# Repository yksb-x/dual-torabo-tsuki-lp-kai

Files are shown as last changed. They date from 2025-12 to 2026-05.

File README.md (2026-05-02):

# Dual-Torabo-Tsuki-LP改（仮）

torabo-tsuki lpは、せきごん氏によって設計された、トラックボール搭載の薄型（ロープロファイル）分割型ワイヤレスキーボードです。
本プロジェクトでは、この torabo-tsuki lp をより自分好みに最適化するため、PCB（プリント基板）の設計変更やケースの改造に取り組むことを目的としています。

## やりたい事
- 自分はMサイズを購入して使用しているが、Sサイズに近い構成で制作する。
- 電池のプラスマイナスを逆に取り付けられる様に配線を変更する。（縦型デザインの乾電池が正しい向きで見える様にする）
- トラックボールはデュアル前提とする。
- その上で、親指キーを左右３つずつ配置する
- トラックボールは19mm球を前提とする。
- ボトムプレート、トラボケースをケースと一体にして、高さ的にトラボが出っ張らない様にする。
- 電池カバーをもっと開閉しやすくする。（現状ノーアイデア）
- 持ち運び用のカバー（弁当箱みたいに上から被せる）
- テンティング（上記のカバーを左右逆にして底側から被せるとテンティングで使えます。みたいなやつ）

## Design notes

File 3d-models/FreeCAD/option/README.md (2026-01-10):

# シンプルケース

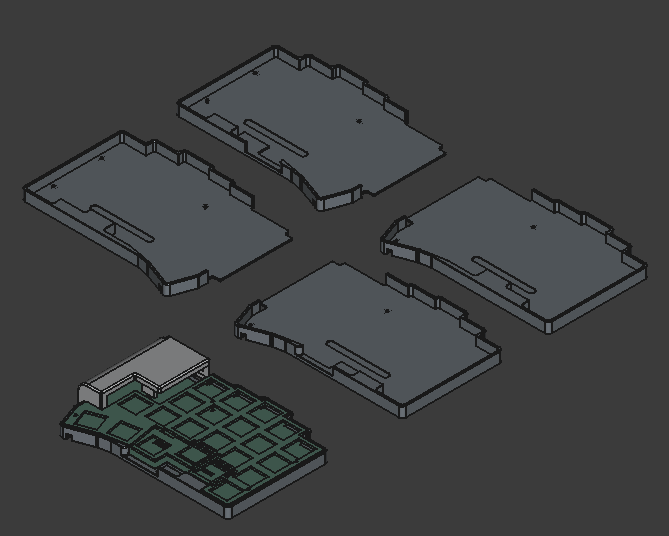
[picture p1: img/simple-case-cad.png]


S/M/Lに対応したケースの設計データです。FreeCADで開いて、スプレッドシートの`case_w_offset`を19にするとMサイズ用、`case_w_offset`と`case_h_offset`を19にするとLサイズ用になります。

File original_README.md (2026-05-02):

# torabo-tsuki LP

torabo-tsuki LP（トラボ付きLP）はトラックボール付きの無線分割キーボードキットです。

トラックボール(25 or 19mm)の高さを低く抑えることで、キーを打つときや持ち運びの邪魔になりにくくなっています。
無線接続に適したハードウェア・ソフトウェア構成により低消費電力を実現しており、連続して数か月間使用可能です。バッテリーは乾電池なので、残量や安全性を気にしながら定期的に充電する必要がありません。

[BOOTH](https://nogikes.booth.pm/items/7200248)にて販売中です。

**MX版の情報は[こちら](https://github.com/sekigon-gonnoc/torabo-tsuki)**

|||
|-|-|
|Sサイズ, 右25mmボール, ケースなし|Sサイズ, 右25mmボール, ケースなし|
|||
|Sサイズ, 右19mmボール, ケースなし|Sサイズ, 右19mmボール, ケースなし|
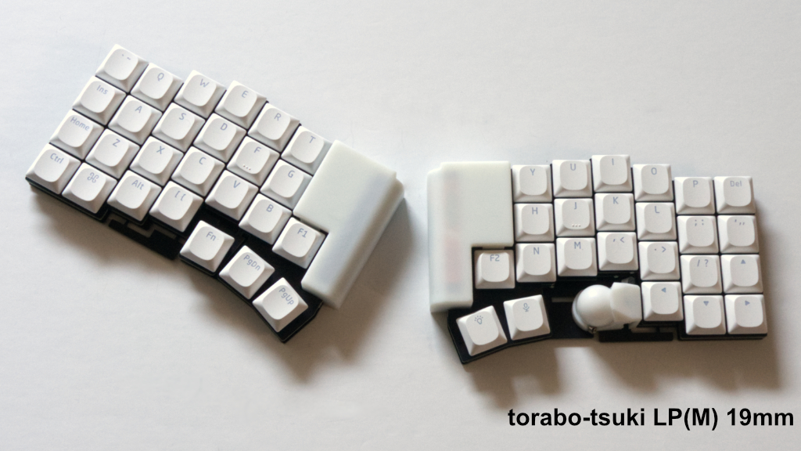
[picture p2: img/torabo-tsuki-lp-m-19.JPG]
|||
|Mサイズ, 右19mmボール, ケースなし||
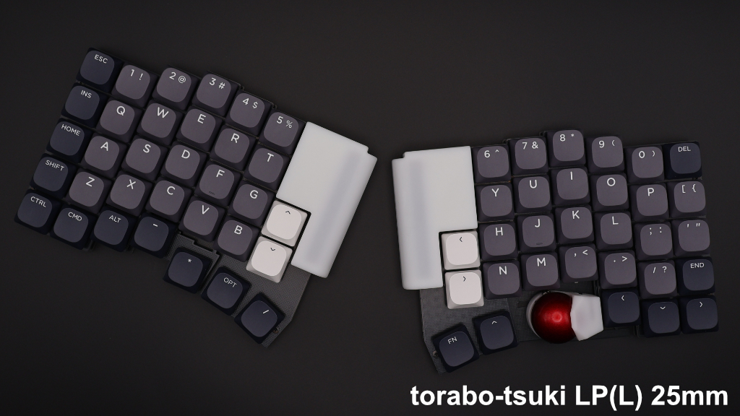
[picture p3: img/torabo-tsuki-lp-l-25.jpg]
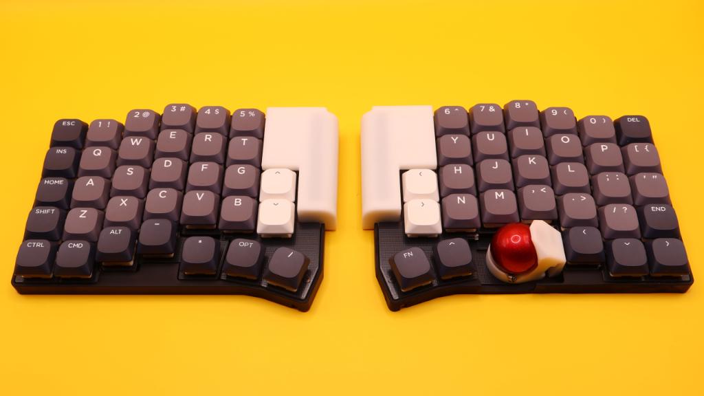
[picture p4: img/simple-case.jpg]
|||
|Lサイズ, 右25mmボール, ケースなし|Lサイズ, シンプルケース|
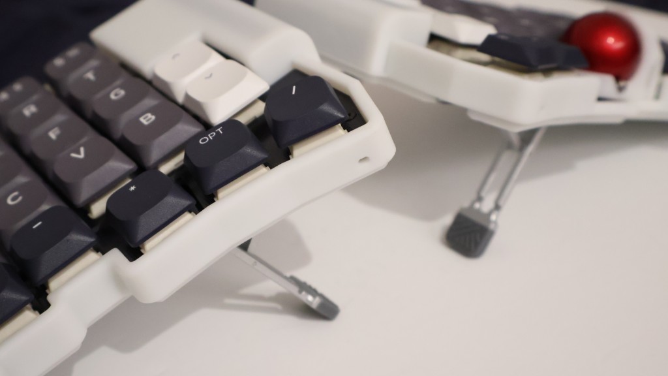
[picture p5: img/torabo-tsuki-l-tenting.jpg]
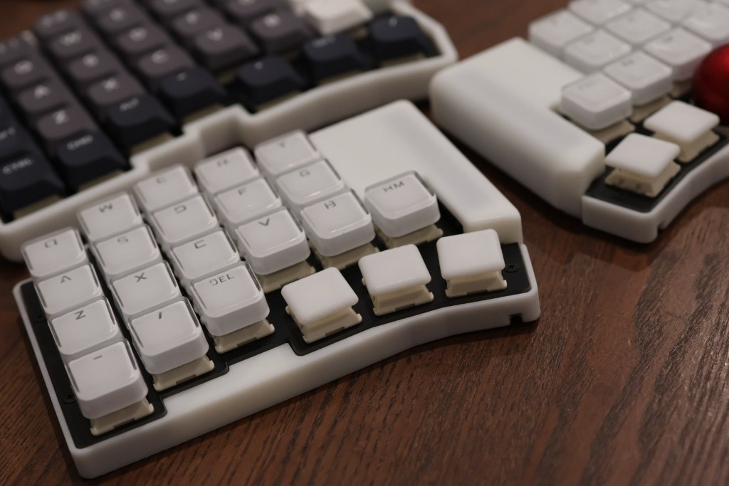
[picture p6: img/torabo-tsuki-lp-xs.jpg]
|||
|Lサイズ, テンティングケース|XSサイズ, 右25mmボール, シンプルケース|

## [ビルドガイド](build-guide.md)

## 特徴

* 主要部品実装済み
  * ソケットやダイオードなどの部品は実装済みです。半田付けが必要な部品は電池ボックスだけです。
* 乾電池各1本で長期間動作
  * Ni-MH電池またはアルカリ電池で動作します。
  * 無線での使用にあわせて調整されたハードウェア・ソフトウェア構成により、乾電池でも数か月間利用できます。
* トラックボールの設置位置が調整可能
  * トラックボールを取り付ける位置を調整して、自分にとって一番操作しやすい位置に設置できます。ボールの高さを抑えたことでキーを打つときの邪魔になりにくなっています。
  * 左トラックボール、デュアルトラックボールにすることもできます。
  * トラックボールのサイズは25mmまたは19mmから選択できます。
* ZMK対応
  * keymap-editorやZMK Studioを使用して簡単にキーマップが変更できます。

## 使用上の注意

* 異臭や煙が出たときは、ただちに使用を中止して電源を切り電池を抜いてください。
* 電池から漏れた液が目に入った場合は、失明する恐れがあるのですぐにきれいな水でよく洗い、医師の診断を受けてください。
* 電池の+-を正しくセットしてください。
* 使い切った電池は速やかに取り出してください。
* 長期間使用しない場合は電池を取り出してください。

## 設計データについて

本リポジトリで基板・トラックボールケース・電池カバーの設計データを公開しています。

ライセンスにしたがって自由に利用していただいて構いませんが、問い合わせには対応しません。

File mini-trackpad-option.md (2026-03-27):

# ミニトラックパッドオプション

トラックボールを付けていない側の電池カバーに、小型のトラックパッドを取り付けるオプションです。

デフォルトでは高分解能スクロールに利用できます。

## オプションキットに含まれているもの

* ミニトラックパッド
* 150mm FPC

## オプションパーツ以外に必要なもの

* 両面テープ（はがしやすいタイプがおすすめです）

## 組み立て

* [トラックパッド対応の電池カバー](3d-models/STL/option/mini-trackpad/)を作成する
  * FDM方式で作成する場合、インフィルを100%にしないと正しく動作しない可能性が高いです。（JLCのSLA方式で製造したもののみ動作確認しています）
* 両面テープをトラックパッドの全面に貼りつけて、電池カバーに取り付ける

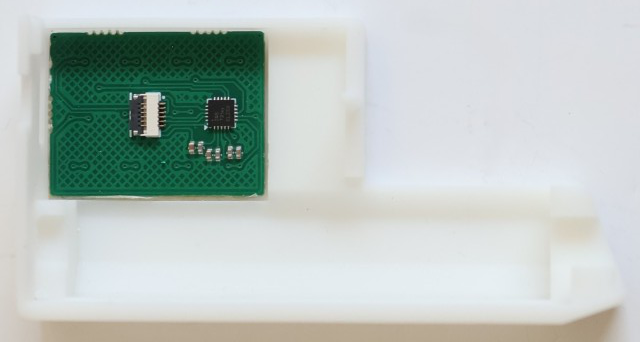
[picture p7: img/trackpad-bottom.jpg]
  ||
  |-|

* FPCケーブルを電池ボックスの側面に通し、キーボードとトラックパッドを接続する

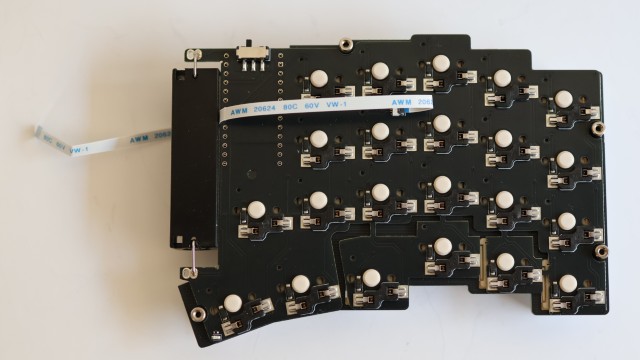
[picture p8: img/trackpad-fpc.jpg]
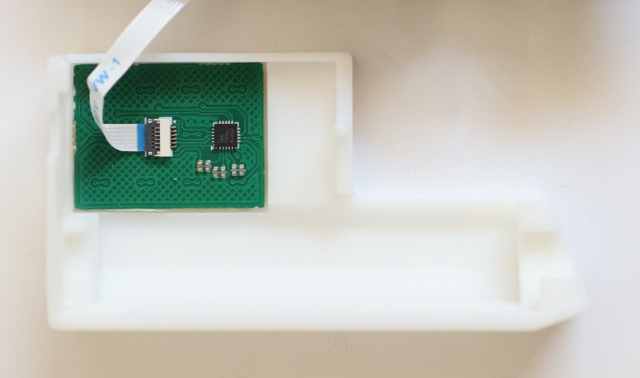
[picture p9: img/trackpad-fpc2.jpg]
  |||
  |-|-|

* 電池カバーをキーボード本体に取り付ける
  * FPCケーブルがBMP Boostのアンテナ部を覆ったり、コンスルーと電池カバーの間に挟まったりしないように注意してください 

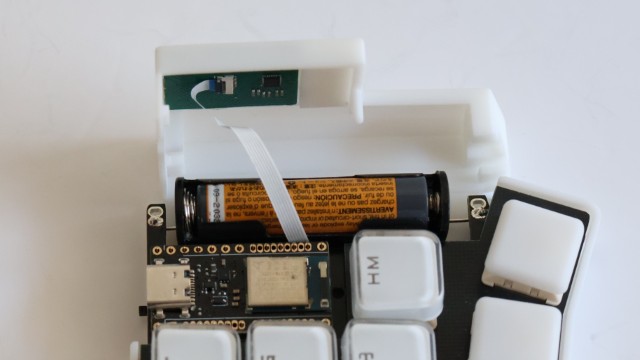
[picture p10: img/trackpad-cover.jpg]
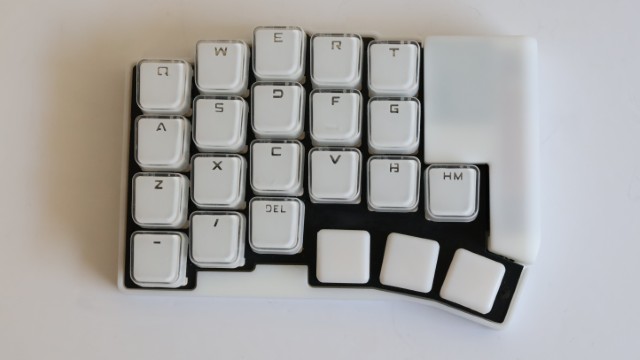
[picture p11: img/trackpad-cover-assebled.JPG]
  |||
  |-|-|

## ファームウェア

[build.yaml](https://github.com/sekigon-gonnoc/zmk-keyboard-torabo-tsuki-lp/blob/master/build.yaml)を編集し、トラックボール側のスニペットに`input-split-listener`、トラックパッド側のスニペットに`input-trackpad-mini`を追加してビルド

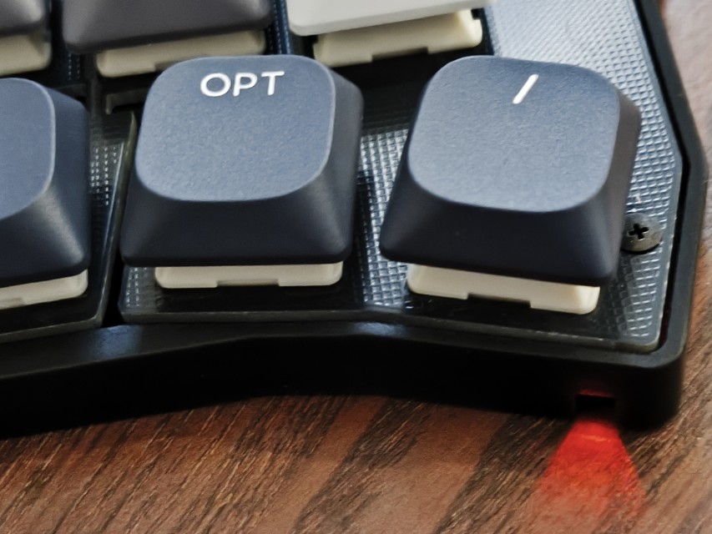
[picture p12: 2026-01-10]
img/simple-case-led.jpg

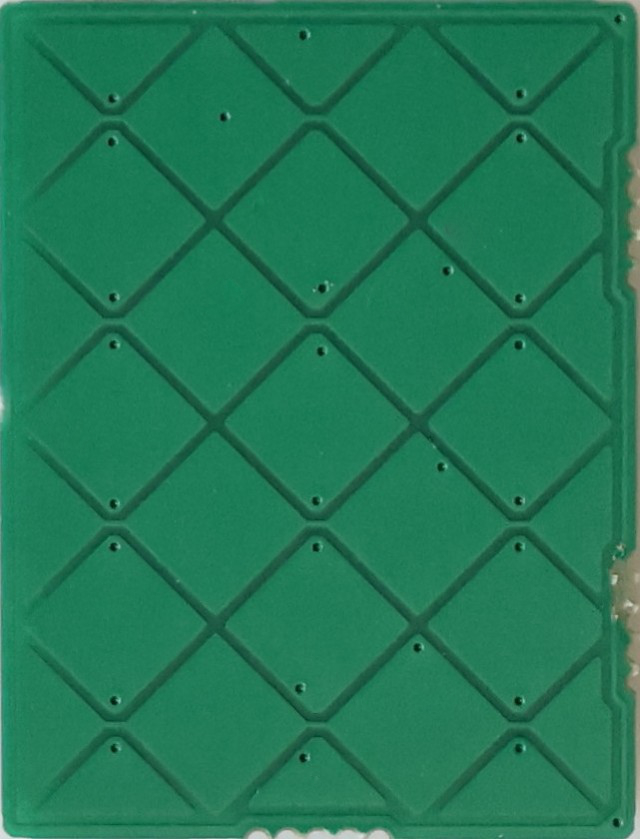
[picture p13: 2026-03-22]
img/trackpad-top.jpg

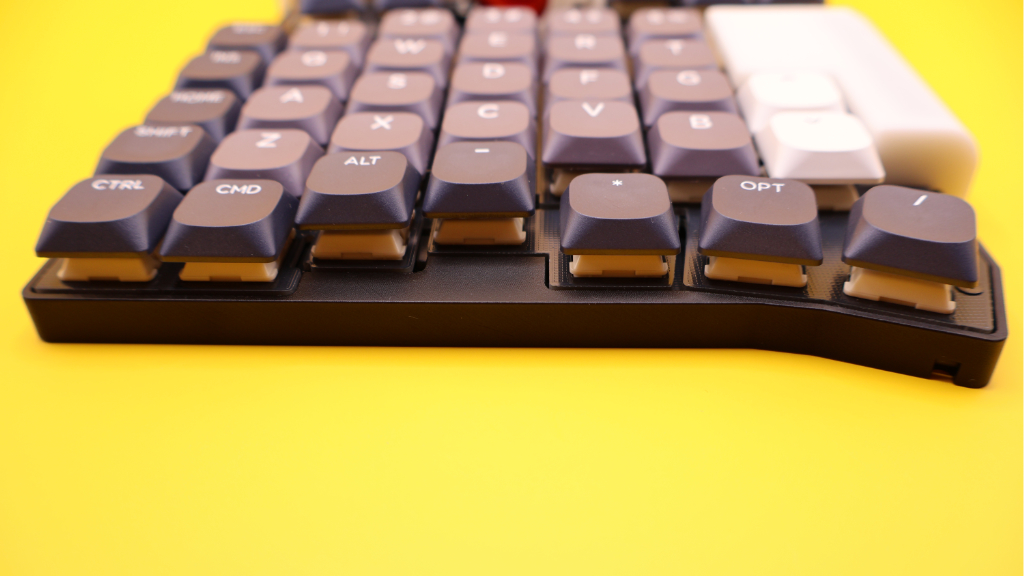
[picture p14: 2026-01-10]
img/simple-case-front.jpg

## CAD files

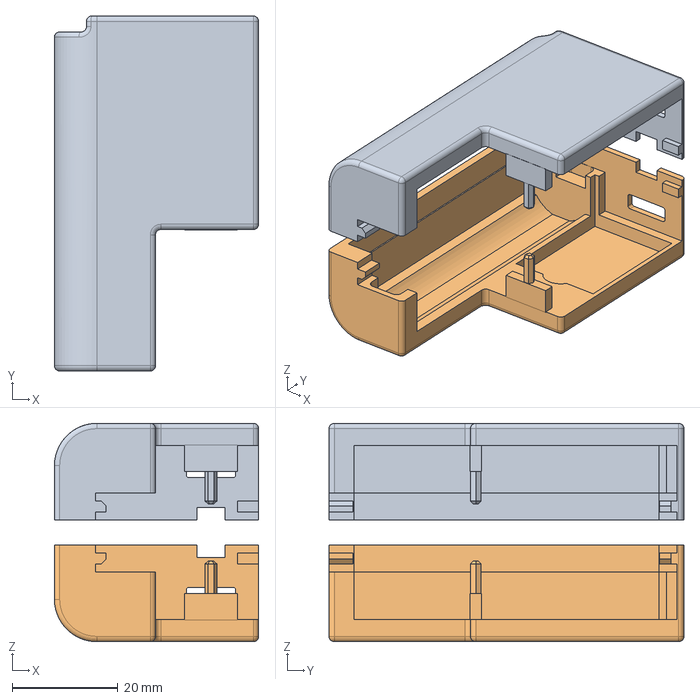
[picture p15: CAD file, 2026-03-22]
3d-models/FreeCAD/option/controller-cover-aa-trackpad.FCStd
38.5 x 67.0 x 41.2 mm
Body (Mirror #1)

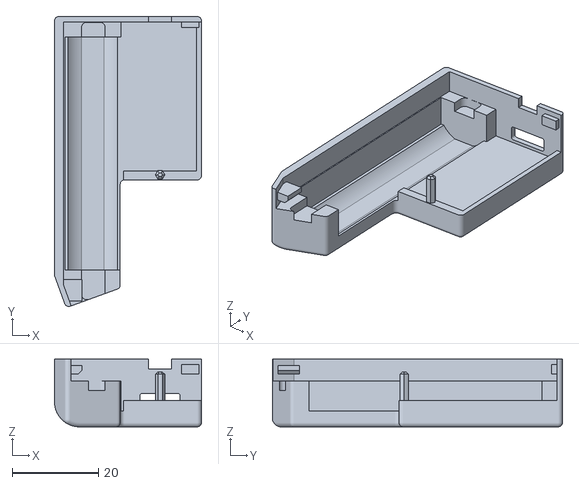
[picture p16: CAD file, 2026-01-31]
3d-models/STL/controller-cover-aaa-xs-Body-mirror.stl
34.1 x 67.2 x 15.7

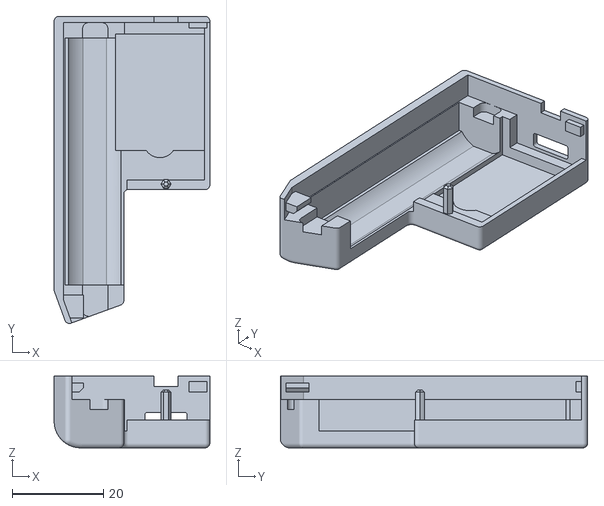
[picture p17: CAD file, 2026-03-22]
3d-models/STL/option/mini-trackpad/controller-cover-aaa-trackpad-xs-Body-mirror.stl
34.1 x 67.2 x 15.7

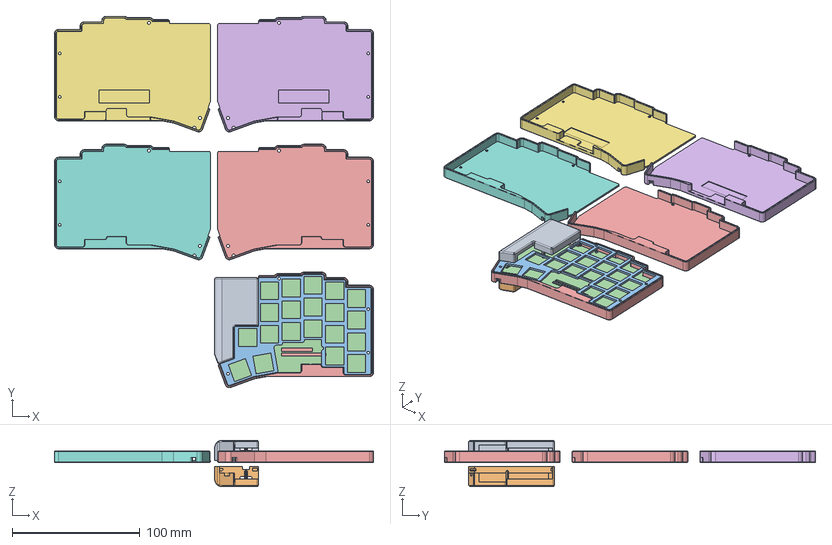
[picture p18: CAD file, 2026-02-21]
3d-models/FreeCAD/option/torabo-tsuki-lp-xs-simple-case.FCStd
249.4 x 290.4 x 36.2 mm
Body (Mirror #1)
torabo-tsuki-lp-XS-top_PCB
torabo-tsuki-lp-XS-bottom_PCB
case-key x 2
case-trackball x 2
case-trackball001 (Mirror #2)
case-key001 (Mirror #3)

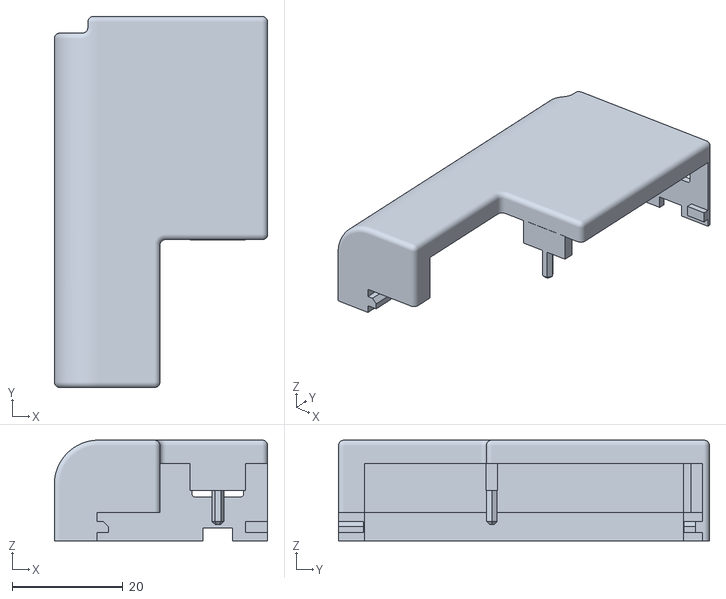
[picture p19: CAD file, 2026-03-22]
3d-models/STL/option/mini-trackpad/controller-cover-aa-trackpad-Body.stl
38.5 x 67.0 x 18.2

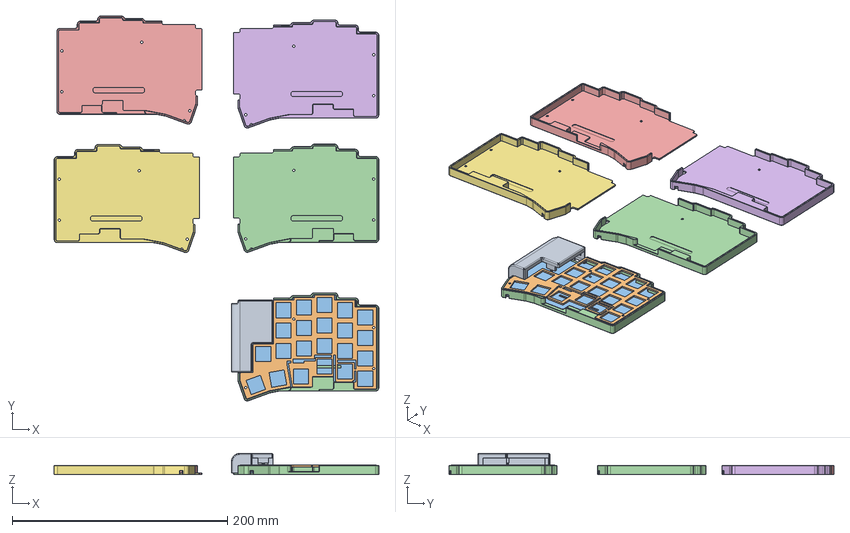
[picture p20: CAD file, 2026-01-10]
3d-models/FreeCAD/option/torabo-tsuki-lp-simple-case.FCStd
301.7 x 357.8 x 19.7 mm
torabo-tsuki-lp-S-top_PCB
torabo-tsuki-lp-S-bottom_PCB
トラックボール側 x 2
トラックボール側001 (Mirror #2)
キー側
キー側001 (Mirror #3)

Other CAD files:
3d-models/FreeCAD/option/controller-cover-aaa-trackpad-xs.FCStd
3d-models/STL/controller-cover-aaa-xs-Body.stl
3d-models/STL/option/mini-trackpad/controller-cover-aaa-trackpad-xs-Body.stl
3d-models/STL/option/mini-trackpad/controller-cover-aa-trackpad-Body-mirror.stl

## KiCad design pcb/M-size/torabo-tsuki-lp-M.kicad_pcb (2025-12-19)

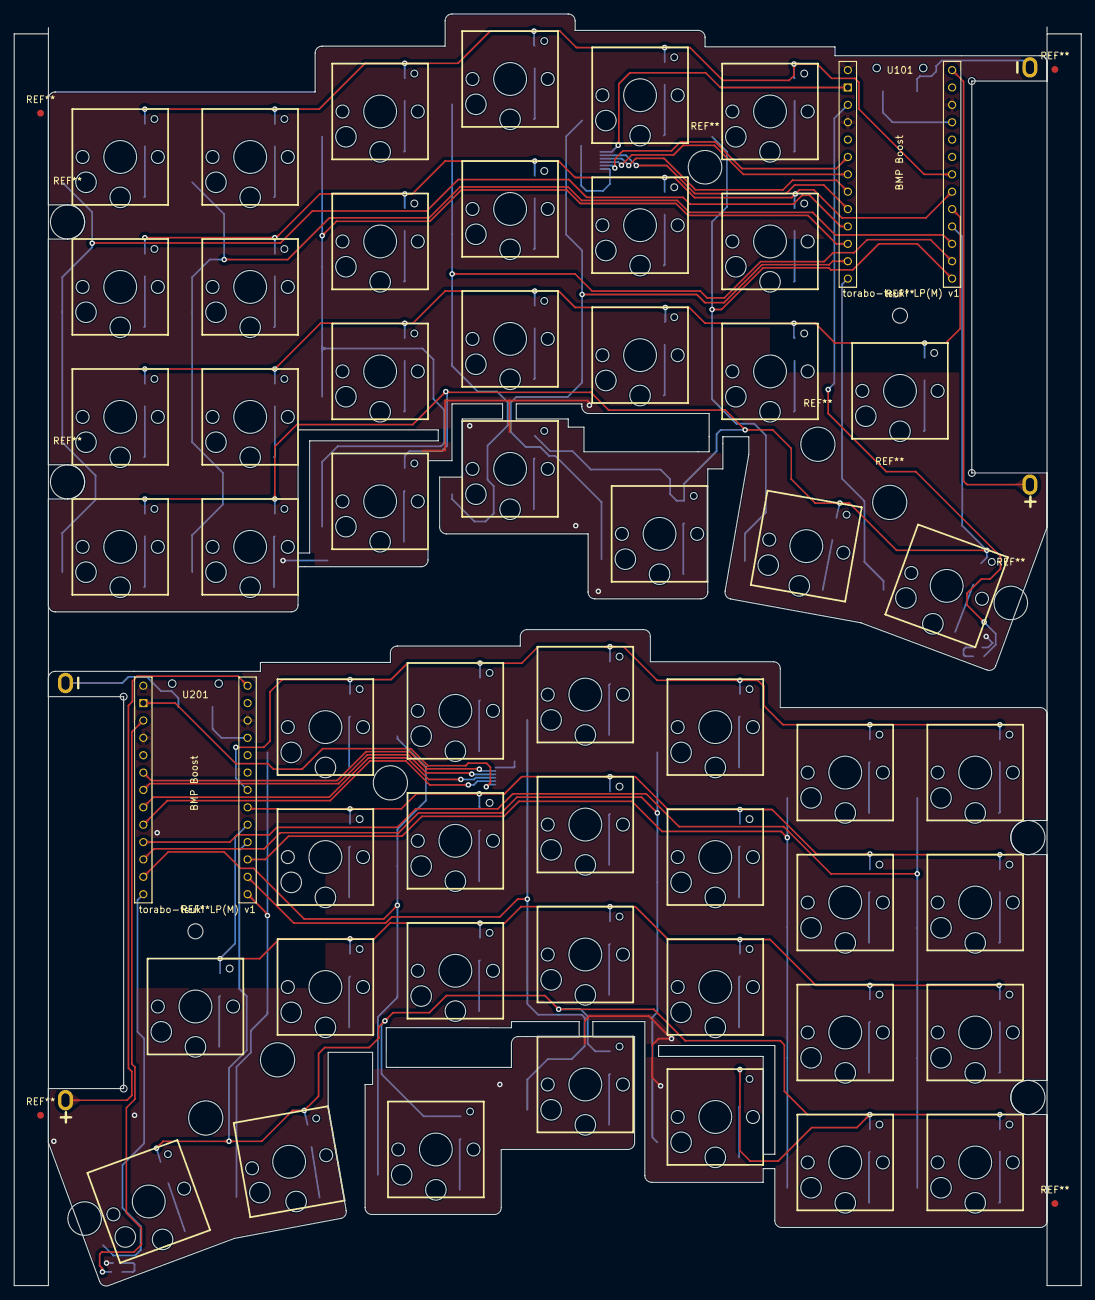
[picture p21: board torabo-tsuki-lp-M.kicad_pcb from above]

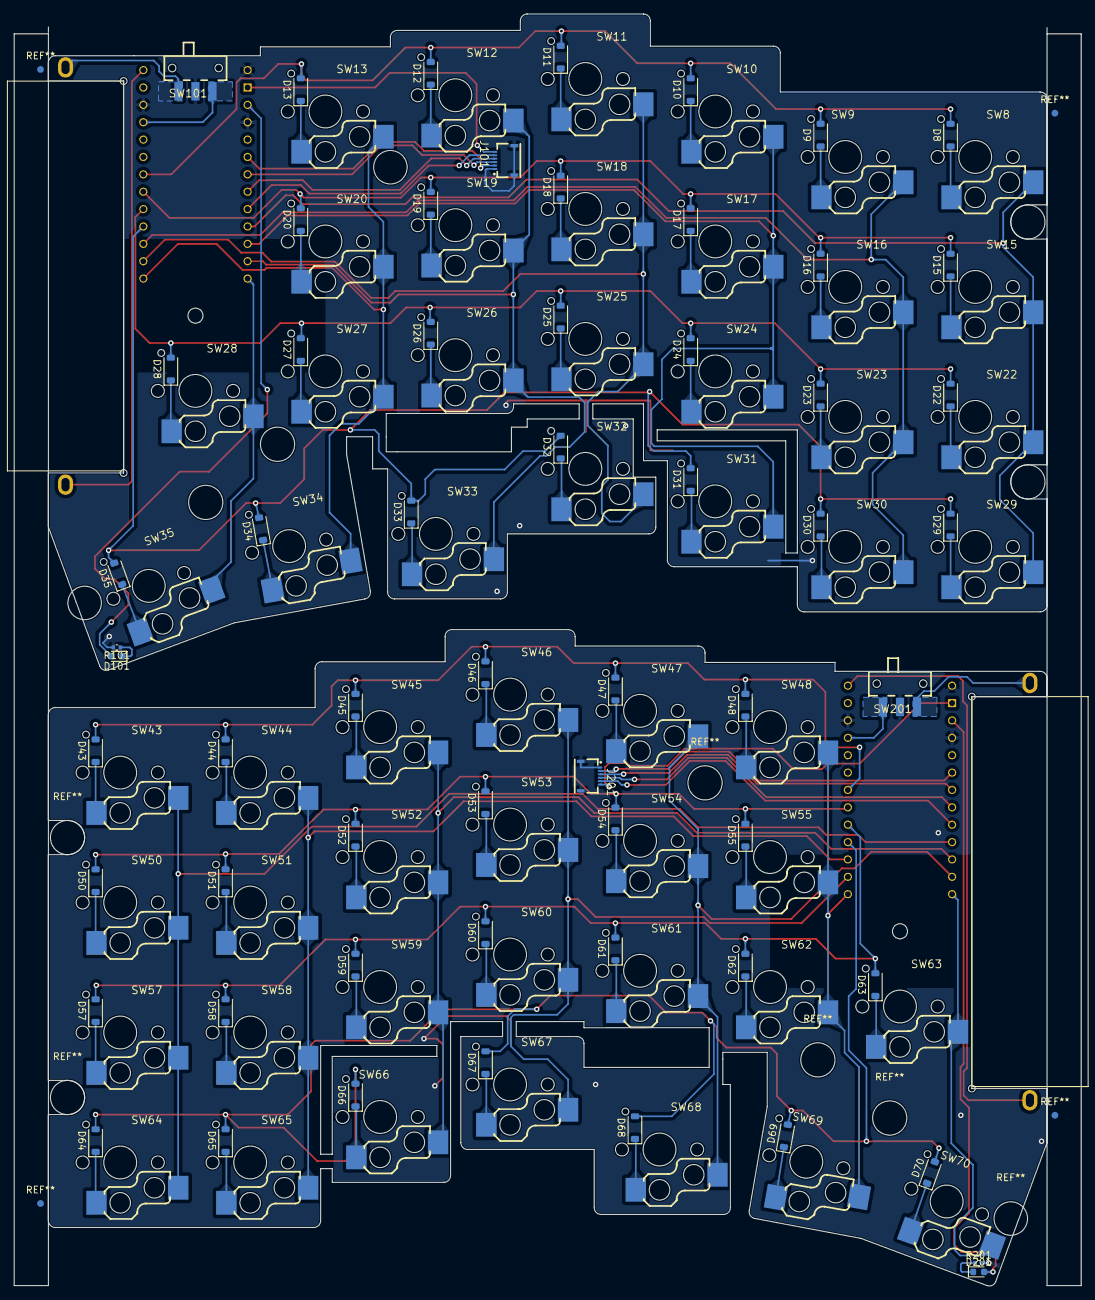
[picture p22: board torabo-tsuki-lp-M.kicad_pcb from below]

Board: 2 copper layers, 156.0 x 186.0 mm, 116 parts (114 on the bottom side), 93 nets.

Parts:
BT101, BT201: Battery_Cell; battery_holder
D8, D9, D10, D11, D12, D13, D15, D16, D17, D18, D19, D20, D22, D23, D24, D25, D26, D27, D28, D29, D30, D31, D32, D33, D34, D35, D43, D44, D45, D46, D47, D48, D50, D51, D52, D53, D54, D55, D57, D58, D59, D60, D61, D62, D63, D64, D65, D66, D67, D68, D69, D70: D_Small; D_SOD-123
D101, D201: LED_Small; LED_0603_1608Metric
J101, J201: Conn_01x06_MountingPin; GT-F0501SR10-06S1101
R101, R201: 330; R_0402_1005Metric
SW8, SW9, SW10, SW11, SW12, SW13, SW15, SW16, SW17, SW18, SW19, SW20, SW22, SW23, SW24, SW25, SW26, SW27, SW28, SW29, SW30, SW31, SW32, SW33, SW34, SW35, SW43, SW44, SW45, SW46, SW47, SW48, SW50, SW51, SW52, SW53, SW54, SW55, SW57, SW58, SW59, SW60, SW61, SW62, SW63, SW64, SW65, SW66, SW67, SW68, SW69, SW70: SW_Push; CHOC_V2_SOCKET_HANDSOLDERING
SW101, SW201: SW_SPDT; SW-SMD_K3-1280S-F1
U101, U201: BLEMicroPro

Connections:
+BATT: BT101.1 (+), BT201.1 (+), U101.26 (BAT), U201.26 (BAT)
/left/BOOT: SW101.3 (C), U101.23 (BOOT)
/left/COL0: SW8.1, SW15.1, SW22.1, SW29.1, U101.10 (22)
/left/COL1: SW9.1, SW16.1, SW23.1, SW30.1, U101.16 (47)
/left/COL2: SW10.1, SW17.1, SW24.1, SW31.1, U101.11 (23)
/left/COL3: SW11.1, SW18.1, SW25.1, SW32.1, U101.15 (10)
/left/COL4: SW12.1, SW19.1, SW26.1, SW33.1, U101.12 (32)
/left/COL5: SW13.1, SW20.1, SW27.1, SW34.1, U101.14 (9)
/left/COL6: SW28.1, SW35.1, U101.13 (35)
/left/CS: J101.5, U101.9 (20)
/left/LED: D101.2 (A), U101.3 (11)
/left/MOTION: J101.4, U101.8 (19)
/left/ROW1: D8.2 (A), D9.2 (A), D10.2 (A), D11.2 (A), D12.2 (A), D13.2 (A), U101.20 (0)
/left/ROW2: D15.2 (A), D16.2 (A), D17.2 (A), D18.2 (A), D19.2 (A), D20.2 (A), U101.19 (30)
/left/ROW3: D22.2 (A), D23.2 (A), D24.2 (A), D25.2 (A), D26.2 (A), D27.2 (A), D28.2 (A), U101.18 (3)
/left/ROW4: D29.2 (A), D30.2 (A), D31.2 (A), D32.2 (A), D33.2 (A), D34.2 (A), D35.2 (A), U101.17 (46)
/left/SCLK: J101.2, U101.6 (18)
/left/SDIO: J101.3, U101.7 (16)
/right/BOOT: SW201.1 (A), U201.23 (BOOT)
/right/COL0: SW43.1, SW50.1, SW57.1, SW64.1, U201.10 (22)
/right/COL1: SW44.1, SW51.1, SW58.1, SW65.1, U201.16 (47)
/right/COL2: SW45.1, SW52.1, SW59.1, SW66.1, U201.11 (23)
/right/COL3: SW46.1, SW53.1, SW60.1, SW67.1, U201.15 (10)
/right/COL4: SW47.1, SW54.1, SW61.1, SW68.1, U201.12 (32)
/right/COL5: SW48.1, SW55.1, SW62.1, SW69.1, U201.14 (9)
/right/COL6: SW63.1, SW70.1, U201.13 (35)
/right/CS: J201.5, U201.9 (20)
/right/LED: D201.2 (A), U201.3 (11)
/right/MOTION: J201.4, U201.8 (19)
/right/ROW1: D43.2 (A), D44.2 (A), D45.2 (A), D46.2 (A), D47.2 (A), D48.2 (A), U201.20 (0)
/right/ROW2: D50.2 (A), D51.2 (A), D52.2 (A), D53.2 (A), D54.2 (A), D55.2 (A), U201.19 (30)
/right/ROW3: D57.2 (A), D58.2 (A), D59.2 (A), D60.2 (A), D61.2 (A), D62.2 (A), D63.2 (A), U201.18 (3)
/right/ROW4: D64.2 (A), D65.2 (A), D66.2 (A), D67.2 (A), D68.2 (A), D69.2 (A), D70.2 (A), U201.17 (46)
/right/SCLK: J201.2, U201.6 (18)
/right/SDIO: J201.3, U201.7 (16)
GND: J101.1, J101.MP (MountPin), J201.1, J201.MP (MountPin), R101.2, R201.2, SW101.2 (B), SW201.2 (B), U101.1 (GND), U101.4 (GND), U101.24 (GND), U201.1 (GND), U201.4 (GND), U201.24 (GND)
unnamed: BT101.2 (-), SW101.1 (A)
unnamed: BT201.2 (-), SW201.3 (C)
unnamed: D8.1 (K), SW8.2
unnamed: D9.1 (K), SW9.2
unnamed: D10.1 (K), SW10.2
unnamed: D11.1 (K), SW11.2
unnamed: D12.1 (K), SW12.2
unnamed: D13.1 (K), SW13.2
unnamed: D15.1 (K), SW15.2
unnamed: D16.1 (K), SW16.2
unnamed: D17.1 (K), SW17.2
unnamed: D18.1 (K), SW18.2
unnamed: D19.1 (K), SW19.2
unnamed: D20.1 (K), SW20.2
unnamed: D22.1 (K), SW22.2
unnamed: D23.1 (K), SW23.2
unnamed: D24.1 (K), SW24.2
unnamed: D25.1 (K), SW25.2
unnamed: D26.1 (K), SW26.2
unnamed: D27.1 (K), SW27.2
unnamed: D28.1 (K), SW28.2
unnamed: D29.1 (K), SW29.2
unnamed: D30.1 (K), SW30.2
unnamed: D31.1 (K), SW31.2
unnamed: D32.1 (K), SW32.2
unnamed: D33.1 (K), SW33.2
unnamed: D34.1 (K), SW34.2
unnamed: D35.1 (K), SW35.2
unnamed: D43.1 (K), SW43.2
unnamed: D44.1 (K), SW44.2
unnamed: D45.1 (K), SW45.2
unnamed: D46.1 (K), SW46.2
unnamed: D47.1 (K), SW47.2
unnamed: D48.1 (K), SW48.2
unnamed: D50.1 (K), SW50.2
unnamed: D51.1 (K), SW51.2
unnamed: D52.1 (K), SW52.2
unnamed: D53.1 (K), SW53.2
unnamed: D54.1 (K), SW54.2
unnamed: D55.1 (K), SW55.2
unnamed: D57.1 (K), SW57.2
unnamed: D58.1 (K), SW58.2
unnamed: D59.1 (K), SW59.2
unnamed: D60.1 (K), SW60.2
unnamed: D61.1 (K), SW61.2
unnamed: D62.1 (K), SW62.2
unnamed: D63.1 (K), SW63.2
unnamed: D64.1 (K), SW64.2
unnamed: D65.1 (K), SW65.2
unnamed: D66.1 (K), SW66.2
unnamed: D67.1 (K), SW67.2
unnamed: D68.1 (K), SW68.2
unnamed: D69.1 (K), SW69.2
unnamed: D70.1 (K), SW70.2
unnamed: D101.1 (K), R101.1
unnamed: D201.1 (K), R201.1
VCC: J101.6, J201.6, U101.2 (8), U201.2 (8)

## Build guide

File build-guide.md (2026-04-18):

## 同梱品

| 名称 | 数  |
| --- | --- |
| メイン基板 | 1 |
| トッププレート | 2 |
| ボトムプレート | 2 |
| 電池ボックス(単三 or 単四) | 2 |
| スペーサー(4.5mm) | 8 |
| ねじ(M2x3.5) | 18  |
| **トラックボール部品** | |
| トラックボールセンサー(14mmマウスセンサーモジュール) | 1 |
| フレキシブルケーブル(0.5mmピッチ、6P、100mm、電極同一面) | 1 |
| ベアリング(4x1.5x2 mm) | 3 |
| ねじ(M1.4) | 3 |
| **BMP Boost同梱の場合** | |
| BMP Boost | 2 |

## 別途必要な部品

| 名称 | 数 | 補足 |
| --- | ----- | --- |
| キースイッチ(Choc V2) | 42(S, XS), 50(M), 64(L) | |
| キーキャップ | 適量  | |
| 25mmトラックボール交換球  or 19.05mm POMボール | 1 | |
| コンスルー | 4 | 13ピン（高さ2.5mm）を使用してください。欠品している場合は12ピンを5個買って、1個を切り離して使ってください |
| 電池カバー、トラックボールケース(25mm or 19mm) | 1式 | 3Dプリントサービスや自前で出力してください。JLC3DPだと送料込みで$5くらいで製造できます（詳細は後述） |
| ゴム足 | 8 | GRIPLUSなど薄型の物がおすすめです |
| 乾電池 | 2 | S,M,Lは単三、XSは単四、Ni-MH可。USBで充電できるリチウム電池内蔵のものを使う場合、必ずキーボードから取り外してから充電してください |
| **オプション** |||
|ケース| 1式 | [シンプルケース](3d-models/STL/option)や有志が公開・販売しているデータを装着できます |
| **BMP Boost別売りの場合** | | |
| BMP Boost | 2 | BLE Micro Pro (無印)は使用できません。入手先:[BOOTH](https://booth.pm/ja/items/1177319), [遊舎工房](https://shop.yushakobo.jp/products/10737) |

## 必要な工具
- はんだごて、はんだ
- ニッパー
- ペンチ
- ドライバー
- （やすり）
- PC
- USBケーブル

## 3Dプリント部品の製造(JLC3DP利用)

[JLC3DP](https://jlc3dp.com/jp/3d-printing-quote)にアクセスします。

[3d-models/STL](3d-models/STL/)フォルダのSTLファイルの中身をJLC3DPにアップロードします。トラックボールケースはサイズが2種類あります。製造時に片方に決めてもいいですし、両方頼んで届いてから考えてもいいです。

電池カバーは、S,M,Lの場合はaaを、XSの場合はaaaを使用してください。

また、[シンプルケース](3d-models/STL/option)や有志が公開・販売しているデータを一緒に製造することもできます。



電池カバー、トラックボールケースについての商品概要は`Enclosure..`から`Plastic Enclosure`を選択します。
ケースについては`Office Appliance...`から`Plastic Keyboard Enclosure`を選択してください。



モデルのサムネイルの下に`印刷リスク`の表示がある場合は`はい`をチェックしてください。



カートに保存し、注文手続きを進めます。配送方法はOCSを選択すると2ドルで配送してもらえます（2025年7月時点、月3回まで）。

発注履歴が表示されるようになった状態で数分経ってからタブをリロードすると、ファイル名の横に!マークが表示されることがあります。

その場合は!マークをクリックし、`はい`を選択してください。

|  |  |
| --- | --- |

JLC3DPによるレビュー中にメールで問い合わせが来る場合がありますが、そのまま製造するように依頼してください。
気になる人は自分でCADデータを修正してください。

## 組立手順

### メイン基板のレール部分を折って切り離す



### メイン基板・トッププレートのトラックボール搭載部分と、トラックボールを搭載しないほうのボトム基板の余剰部分を切り離す

シンプルケースを装着する場合は、ボトムプレートは両側とも余剰部分を切り離します。

ニッパーでそのまま切り離せない場合は、表裏に切れ目を入れてから折り取ることもできますが、ほかの配線を傷つけないように注意してください。

> [!caution]
> 向きを間違えないように注意してください。下記画像は右側にトラックボールを搭載する例です。



### 電池ボックスをはんだ付けする

* 電池ボックスの足を折り曲げます。
  * XSに単四電池ケースを取り付ける場合は基板上のマークよりすこし上に寄せてください。基板の穴はBMP Boost側を使います。
* ボトムプレートに電池ボックスを載せ、その上からメイン基板を載せます。向きに注意してください。
* 余った足を短く切ってからはんだ付けします。メイン基板とボトム基板がぴったりくっついた状態ではんだ付けするようにしてください。

|||
|-|-|
|||

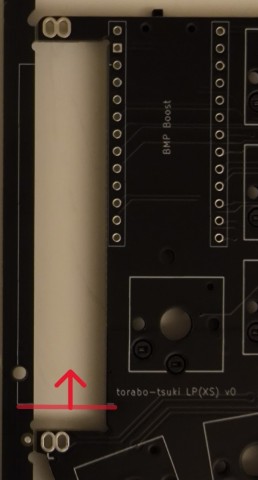
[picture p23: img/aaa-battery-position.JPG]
||
|-|
|単四電池ケースの取り付け位置|

### トッププレート・メイン基板にスイッチを差し込む



### メイン基板にBMP Boostをコンスルーで取り付ける

* はんだ付けは不要です。
* コンスルーの向きは揃えてください。

|||
|-|-|

### ファームウェアを書きこむ

* スイッチをOFFにした状態で、BMPをPCにUSBケーブルで接続します。
* BLEMICROPROという名前のストレージがマウントされたら、中身にINFO_UF2.TXTがあることを確認してください。
* [Releases](https://github.com/sekigon-gonnoc/zmk-keyboard-torabo-tsuki-lp/releases)からファームウェアのuf2ファイルをダウンロードします。
* uf2ファイルを1つ選んでストレージにコピーしてください。トラックボールがあるほうがCentral、ないほうがPeripheralです。
  * たとえば右側トラックボールで組み立てた場合、右手に`torabo_tsuki_lp_right_central`、左手に`torabo_tsuki_lp_left_peripheral`を書き込んでください。
* 書き込みが完了したら一度USBケーブルを抜き、スイッチをONにした状態でUSBケーブルを差し直すとキーボードとして動作します。

### トッププレートにスペーサーをねじ止めする

* スペーサーをトッププレートにねじ止めします。



### トラックボールケースにベアリングをネジで固定する

* ケースに空いている穴にねじを押し込みながら回すようにしてベアリングを固定します。
* ベアリングは多少ガタつきますが問題ありません。



### トラックボールセンサーにケーブルを差し込む

* コネクタのフラップ（黒い部分）を上に持ち上げ、トラックボールのケーブルをしっかり奥まで差し込み、フラップを下げます。
  * [コネクタの操作方法と注意点をよく確認してください](https://www.hirose.com/ja/product/document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)



### トラックボールのケーブルをメイン基板のコネクタに差し込む



### センサーの動作確認をする

* USBケーブルでPCとBMP Boostを接続します。
* センサーのレンズ側を机から2mmくらい浮かせてセンサー基板を動かしたり、レンズの上空を指で動かしたりしてマウスカーソルが動くならば、センサーは正常に動作しています。 
* センサーの動作確認ができたらUSBケーブルは取り外してください。

### トラックボールセンサーをケースに取り付ける

* ケースの中央あたりまで差し込みます。
* 緩すぎてすぐ抜けてしまう場合は紙などを挟んで調節してください。
* きつすぎる場合は背面の突起を削ってください。
* トラックボールの反応が悪い場合には取り付け位置を調整してください。

|||
|-|-|

### ボトムプレートを取り付け、ボトムプレートにトラックボールケースを取り付ける

* シンプルケースを装着する場合はケースも一緒にねじ止めしてください。



### トラックボールケースにボールを入れる

* ボールをケースに押し込んで入れます。

### 電池を入れる

* 電池をケースに入れます。向きに注意してください。

### 電池カバーを付ける

* 外側の爪2箇所(XSは1箇所)をメイン基板にひっかけます。
* 内側の爪（USBコネクタ横の爪）を引っ張りながらメイン基板にひっかけます。

||||
|-|-|-|

* ボトムプレートを外した場合、下の図で赤く示した4箇所で固定されています



### ゴム足を付ける



### キーキャップを取り付ける

**以上で組立は完了です、お疲れさまでした。**

## 使い方

### 電源の説明

* スライドスイッチをON側に切り替えると電源が入ります。電源がONするとLEDが点滅します。
* 有線接続する場合でもスライドスイッチはON側にしてからケーブルを接続してください。OFFの状態で接続した場合はブートローダが起動します。

### LEDの説明

親指のところに赤色LEDがついています。

* 起動時：点滅回数(1~3)でバッテリー残量を示しています
* ペアリング中：ペアリング先を探している間、数秒に1回点灯します。ペアリングが完了すると1回点灯します。



### 無線接続

* 両手のスライドスイッチをONして、接続先のデバイスでペアリングします。

### キーマップを変更する

* [ZMK Studio](https://zmk.studio/)または[Keymap-Editor](https://nickcoutsos.github.io/keymap-editor/)でキーマップが変更できます。
* Keymap-Editorを使用する場合は[zmk-keyboard-torabo-tsuki-lp](https://github.com/sekigon-gonnoc/zmk-keyboard-torabo-tsuki-lp)をクローンして編集してください。
  * Keymap-Editorの仕様によりconfig/info.jsonはLサイズ用になっているため、S,Mサイズには存在しないキーも表示されます。
  * [ファームウェアの書き込み方](#ファームウェアを書きこむ)を参考にして、新しく作ったuf2ファイルを書き込んでください。

## トラブルと対策

* 初期不良による部品交換が必要な場合や、組立ミスのため一部部品だけ購入したい場合はBOOTHからメッセージをお送りください。
* 組立にあたってのトラブルで相談がある場合は本リポジトリのissueに投稿してください。
  * **投稿の前に既存のissueを検索してください**

## FAQ

まずはZMKのドキュメントを確認してください。

### ペリフェラル側をUSB接続してもキー入力できない

* ZMKの仕様です
* セントラルとペアリングしたうえでセントラル側を有線または無線接続してください

### 無線接続に問題がある

* 電源が入っているか確認してください。
* ZMKのドキュメントを確認してください。
* settings_resetのファームウェアを書き込む場合、uf2を書き込むだけでなく、一度再起動が必要です
  * スイッチOFF→USB接続→書き込み→USB外す→スイッチON→USB再接続でsettings_resetのファームウェアが動作して、設定が初期化されます

### トラックボールの動きだしが遅い

* 一定時間ボールを動かさなかった場合にセンサーがスリープ状態になります。スリープ状態の解除に少し時間がかかるため動き出しが遅くなる場合があります。

### トラックボールの動きがおかしい/動かない

* [センサーの位置調整](#トラックボールセンサーをケースに取り付ける)をご確認ください。
* トラックボールのケーブルがコネクタにしっかりささっているか確認してください。
* センサーの仕様として、最大速度24inch/s、最大加速度10Gという制約があります。25mmボールの回転速度に換算すると9回転/sが最大速度で、これを超える速度で回転させた場合にはカーソルが逆方向に動くことがあります。

### 一部のキーが入力できない

* スイッチの足が折れ曲がっていないか、BMP Boostが浮いていないか確認してください。

### トラックボールの移動速度を変えたい/オートマウスレイヤー/スクロールレイヤーを使用したい

* ZMKのinput processorを使用してください。

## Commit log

2025-10-21 Update key switch requirements in build guide
2025-12-19 Add LP(M) info
    [left.kicad_sch, right.kicad_sch, torabo-tsuki-lp-M-top.kicad_pcb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]
2026-01-01 L-sizeのキー数追記
2026-01-10 シンプルケースを追加
    [torabo-tsuki-lp-simple-case.FCStd]
2026-01-31 XSの情報を追加
2026-01-31 Add XS size controller cover STL files and update build guide with battery cover size information
    [controller-cover-aaa-xs-Body-mirror.stl, controller-cover-aaa-xs-Body.stl]
2026-01-31 Update battery box soldering instructions and add installation image for AAA battery case
2026-02-05 Add XS size simple case STL files and update README with new images and descriptions
    [torabo-tsuki-lp-xs-simple-case.FCStd]
2026-02-10 ファームウェアの書き込み方法を追記
2026-02-21 破綻したメッシュを修正
    [torabo-tsuki-lp-xs-simple-case.FCStd]
2026-03-21 Add troubleshooting checklist item for socket connection verification
2026-03-22 ミニトラックパッドの説明を追加
    [controller-cover-aa-trackpad-Body-mirror.stl, controller-cover-aa-trackpad-Body.stl, controller-cover-aa-trackpad.FCStd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]
2026-04-08 issueテンプレートを更新
2026-04-18 Enhance cutting instructions for bottom plate
    Added caution about cutting excess parts to avoid damaging wiring.
2026-05-02 Initialize README with project details and objectives
    Added project description and goals for Dual-Torabo-Tsuki-LP改.
